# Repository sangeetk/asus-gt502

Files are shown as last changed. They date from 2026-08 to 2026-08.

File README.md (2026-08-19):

# ASUS ROG GT502 — custom aluminium front panel with two touchscreens

A 3 mm aluminium replacement front panel for the ASUS ROG GT502, with two
windows for Waveshare touchscreens bonded from behind with 3M VHB tape. Cutting
the metal away (rather than mounting the screens outside it) is what leaves the
touch surface exposed and usable.

## Files

| File | What it is |
| --- | --- |
| `GT502_front_panel_194x384_both_screens.dxf` | **Everything to be cut.** The panel plus the 4 back stiffener strips, nested on one sheet as a single cutting job. Send this to the laser cutter. |
| `CUTTING_SPEC.txt` | Vendor sheet: material, tolerance, kerf, finish, every coordinate. Send with the DXF. |
| `GT502_front_panel_194x384_both_screens_PRINT_1to1.svg` | True-scale check print. See "Before you order". |
| `GT502_front_panel_194x384_both_screens.svg` | Screen preview, with screen glass and active areas shown as reference. |
| `generate_panel_dxf.py` | Generates all four of the above from the constants at the top. Single source of truth. |
| `name_outlines.py` | Frozen outlines for the two name pieces. Generated offline; imported by the script. |
| `hunabku_outline.py` | Frozen outline for the Hunab Ku keyring. Generated by `trace_hunabku.py`; imported by the script. |
| `trace_hunabku.py` | Traces `hunab_ku_source.svg` into the file above and measures its narrowest metal and slot. Run once; not needed to build the panel. |
| `hunab_ku_source.svg` | The source artwork, public domain, from Wikimedia Commons. |
| `ginger_outline.py` | Frozen outline for the "ginger" lettering. Generated by `trace_ginger.py`; imported by the script. |
| `trace_ginger.py` | Traces `ginger_source.png` into the file above. Run once; not needed to build the panel. |
| `ginger_source.png` | The lettering artwork as supplied — white on transparent, so the shape is in its **alpha channel**. |
| `FrontAluminiumPanel.txt` | Measured outer size of the panel. |
| `Waveshare-11inch.png`, `Waveshare-6.25inch.png` | Manufacturer dimension drawings the screen numbers come from. |

Do not hand-edit the DXF or the spec — change a constant in the script and
re-run it, so the drawing, the print sheet and the spec can never disagree.

## The part

Sheet is **194.00 W × 384.00 H**, 3 mm aluminium, 3.0 mm corner radius.
Origin for all coordinates is the **lower-left corner**, X right, Y up.

| Feature | Size | Position (lower-left) |
| --- | --- | --- |
| Upper window — 6.25″, landscape | 147.18 × 68.70, R2 | X 26.41, Y 287.49 |
| Lower window — 11″, portrait | 153.22 × 241.67, R2 | X 23.39, Y 27.81 |
| Mounting holes, 4 off | Ø3.20 through | see below |

The DXF also carries 7 back stiffener pieces nested **inside** the 11″ window —
see "Back stiffener layer" — two name pieces nested inside the 6.25″ window, and
a Hunab Ku keyring plus the "ginger" lettering in what was left of the 11″
window. Sheet extent stays **194 × 384**, so none of them cost extra material.
One job, one sheet, **12 parts delivered**.

Aluminium between the two windows: **18.00 mm**. Both windows sit **3.00 mm
right of the sheet centreline** — this is deliberate, from test-fitting the
first cut sheet. Left and right margins are *not* equal; work to coordinates.

### Mounting holes

| Hole | X, Y | As measured |
| --- | --- | --- |
| top left | 65.00, 371.00 | 65 from left, 13 from top |
| top right | 135.00, 371.00 | 59 from right, 13 from top |
| bottom left | 32.00, 17.00 | 32 from left, 17 from bottom |
| bottom right | 165.00, 17.00 | 29 from right, 17 from bottom |

All to hole **centre**. Not a symmetric pattern: the top pair is 70.00 apart and
3.0 mm off-centre, the bottom pair 133.00 apart and 1.5 mm off-centre. These
came off the case, so they are correct as given rather than tidy.

**All four moved off the A4 1:1 check prints held against the case.** Top left
+2.00 right, top right +1.00 right; bottom left +2.00 right and +1.00 up, bottom
right +1.00 right and +1.00 up. Each pair's two corrections differ, so both
pitches closed — top 71.00 → 70.00, bottom 134.00 → 133.00 — and neither pair is
symmetric about the sheet any more. That is what four independent measurements
against the real case give you; it is not a pattern being nudged.

Both bottom holes are now **1 mm nearer the 11″ glass**, which is the one
clearance these moves eat into — see "Assembly notes".

> **Open item — hole diameter is an assumption.** Ø3.20 is M3 clearance,
> chosen because no fastener was specified. Confirm before cutting; holes are
> the one feature you cannot correct afterwards. Change `HOLE_DIA` if wrong.

## Screens

Numbers taken from the Waveshare drawings in this folder.

| | Glass (outer) | Active area | Bezel |
| --- | --- | --- | --- |
| 11″, portrait | 165.22 × 253.67 | 148.02 × 236.47 | 8.60 all round |
| 6.25″, landscape | 159.18 × 74.70 | 144.18 × 66.60 | 7.50 sides, 4.05 top/bottom |

Each window is smaller than the glass but larger than the active area, so the
metal overlaps the black bezel and no pixels are clipped.

### VHB tape land

The overlap between metal and bezel is the only place tape can go:

| | Land available |
| --- | --- |
| 11″ | 6.0 mm all four edges |
| 6.25″ | 6.0 mm sides, 3.0 mm top and bottom |

**12 mm VHB will not fit anywhere.** The widest bezel on either screen is
8.60 mm, and the 6.25″ has only 4.05 mm top and bottom — this is a limit of the
screens, not of the drawing. Slit 12 mm tape lengthwise into 6 mm strips, or
buy a 6 mm roll (3M 5952 and GPH both come in 6 mm). Never let tape overhang
into a window: the grey foam shows through the glass.

The 6.0 mm land also leaves 2.60 mm of visible black border around the 11″
image (1.50 / 1.05 mm on the 6.25″). That border is your placement tolerance —
VHB gives you exactly one attempt, so it is margin worth keeping.

## Back stiffener layer

A second 3 mm layer bonded to the **back** of the panel to stiffen it. **7
separate pieces**, all nested inside the 11″ window opening — that slug is
scrap anyway, so they use no extra sheet and the total extent stays 194 × 384.
None of it is visible in the finished build.

| Piece | Bounding size | Bonds at | Shape | Holes |
| --- | --- | --- | --- | --- |
| left strip A | 17.00 × 192.00 | X 0, Y 0 | rect, R3 bottom-left | — |
| left strip B | 20.00 × 192.00 | X 0, Y 192 | **stepped** 17→20, R3 top-left | — |
| right strip A | 11.00 × 192.00 | X 183, Y 0 | rect, R3 bottom-right | — |
| right strip B | 14.00 × 192.00 | X 180, Y 192 | **stepped** 11→14, R3 top-right | — |
| top strip | 160.00 × 24.50 | X 20, Y 359.50 | rect | 2 |
| bottom strip | 166.00 × 21.50 | X 17, Y 0 | rect | 2 |
| mid bar | 160.00 × 8.50 | X 20, Y 275.74 | rect | — |

Three details that are easy to lose, and all three are in the cutting spec:

- **The side pieces each carry one R3 corner** — the one that lands at a panel
  corner. That lets them run the panel's full 384 mm (2 × 192) instead of
  stopping at the corner arc tangents, which cost 6 mm per side.
- **The two upper side pieces are stepped, not rectangular.** They are 17/11 mm
  wide alongside the 11″ glass and widen to 20/14 mm above it. See below.
- **The three horizontals are drawn rotated 90°** from how they are fitted, to
  nest inside the window. Their holes rotate with them.

### Why the side pieces step

The 6.25″ glass is 159.18 wide against the 11″'s 165.22, so it sits 3.02 mm
inboard on each side. A full-height rectangular rail has to be sized for the
wider screen, which leaves a 3.41 mm gap beside the top screen. Stepping the
rail above the 11″ glass closes that to **0.41 mm** without adding pieces or
butt joints. The step sits at Y 275.74 — the top of the 11″ glass plus 0.25 mm
of air, the same line the mid bar sits on.

### Clearances — all four edges run tight

Widths are capped from the live glass positions, not chosen freely: the screens
bond to the panel's own cutouts, so a piece reaching under the glass would sit
that screen on a 3 mm step and tilt it.

| Edge | Free margin | Cut at | Clearance |
| --- | --- | --- | --- |
| left, lower | 17.39 | 17.00 | 0.39 |
| left, upper | 20.41 | 20.00 | 0.41 |
| right, lower | 11.39 | 11.00 | 0.39 |
| right, upper | 14.41 | 14.00 | 0.41 |
| top | 24.81 | 24.50 | 0.31 |
| bottom | 21.81 | 21.50 | 0.31 |
| mid bar | 9.00 gap | 8.50 | 0.25 each side |

**Everything hangs off where the 11″ screen ends up.** Six of those clearances
are under 0.5 mm, and they are all measured from that screen's glass. Bond the
11″ first, measure the actual gaps, then fit the pieces — they are plain
stock you can file, the screen is not.

### The mid bar

Sits in the 9.00 mm gap between the two screens, 8.50 wide with 0.25 mm of air
each side. Its job is to give the 6.25″ screen a bottom edge to sit down onto —
nothing else locates that screen vertically, since it is a small screen in a
large window with only 3 mm of bezel overlap top and bottom. With the 24.50 mm
top strip above it, the 6.25″ glass is captured in a 75.265 mm slot for a
74.700 mm glass: **0.565 mm total slack**.

Fit order matters: **mid bar before the 6.25″ screen**, or it is no use as a
datum. Full sequence — 11″ screen, mid bar, 6.25″ screen, then the perimeter
pieces.

### Holes in the pieces

Top and bottom strips carry matching Ø3.20 holes so one screw passes through
both layers. Offsets are from each piece's own lower-left corner **as drawn**:

| Piece | Holes | Pitch |
| --- | --- | --- |
| top strip | (13.00, 45.00) and (13.00, 115.00) | 70.00 |
| bottom strip | (4.50, 15.00) and (4.50, 148.00) | 133.00 |

Those pitches match the panel's top and bottom hole pitches exactly. The four
side pieces have no holes.

### Nest

The 7 pieces occupy 140.50 of the 143.22 mm available across the window, with
4 mm between pieces and a 5 mm margin to the window edge. **That is full** —
there is no room for another piece or another width increase without starting a
second row. The unused height above the pieces is the only spare space left,
and it is now full too: 65.22 × 61.67 above the three shorter pieces holds the
keyring, and the 79.61 × 35.67 band above the four tall ones holds the
lettering.

The spec tells the cutter to **cut all 7 pieces before the window outline that
surrounds them** — once that contour is cut, the slug they sit in drops away.

## Hunab Ku keyring

One more part, cut from the last of the 11″ window slug: the Mayan Hunab Ku
symbol as a keyring, **54.00 mm outside diameter, 60.60 mm overall** with its
lug, drawn at X 112.00, Y 203.35. Ø3.50 keyring hole. It costs no sheet, it
touches nothing, and dropping it changes nothing else — `MEDALLION = False`.

The outline is traced from `hunab_ku_source.svg` (public domain, Wikimedia
Commons) by `trace_hunabku.py`, which flattens the artwork's single even-odd
path, replaces its disc with a true circle, normalises to a 100 mm nominal
diameter, and freezes the result in `hunabku_outline.py`. The panel script only
scales it.

### Its size is set by the artwork, not by taste

Every line in the symbol scales with the disc, and at a 100 mm disc the
narrowest metal is **1.77 mm** and the narrowest slot **1.81 mm** — both in the
eight antennae. Those numbers come off the geometry itself: the tracer
rasterises the finished outline, opens it morphologically, and measures each
surviving thin feature by its own largest inscribed circle.

At the 52 mm the free space allows, that scales to **0.92 mm metal and 0.94 mm
slots**. That is the finest work on the sheet — finer than the 1.1 mm necks in
the name pieces — so the size is pushed as large as the space allows rather
than down to a pocket-sized fob. **A keyring-sized 40 mm version would need
0.7 mm slots and is not worth sending to a cutter.** The spec asks the vendor to
confirm they can hold 0.9 mm in 3 mm aluminium, and to say so rather than
opening the slots out. `MEDAL_MIN_FEATURE` makes the script refuse to draw it
below 0.85 mm.

### Two things added to the artwork

- **The rim is drawn 1.00 mm outside the symbol's own disc** (`MEDAL_RIM_EXTRA`).
  The artwork's outer ring is as thin as everything else in it, and that ring is
  what the keyring hangs off. Doubling it up reads as a slightly heavier rim and
  moves nothing else.
- **A lug on top**, filleted into the disc, carrying the hole — 2.25 mm of metal
  around it. There is nowhere inside the symbol to put a hole: the widest solid
  area in it takes only a 10 mm circle, off to one side, so a hole there would
  deface it *and* hang it crooked.

The piece is **one connected part** — the symbol's material is a single region,
so every internal contour is a hole that drops out and nothing is a loose
island. That is checked, not assumed. Cut it before the 11″ window outline, same
as the stiffener pieces.

## "ginger" lettering

The last free space in the 11″ slug, the band above the tall stiffener strips,
holds the word **"ginger" at 75.91 × 33.71 mm**, drawn at X 30.24, Y 229.80.
One connected part: 1 outer contour and 4 counters that drop out.

It is **traced artwork, not type** — `ginger_source.png` as supplied, which is
white lettering on a transparent background, so the shape lives in the file's
alpha channel and a viewer that flattens it onto white shows a blank page.
`trace_ginger.py` thresholds that alpha, drops the export's specks and pinholes,
traces the pixel boundary exactly, rounds the 0.09 mm staircase off it and
simplifies. No font is involved, so nothing depends on having the typeface.

Two things worth knowing before it is cut:

- **The dot of the "i" is tied on with a 2.5 mm weld tab.** It is a separate
  shape in the artwork, as it is in any script, and without the tab it arrives
  as a loose disc. Same trick, same width, as the tabs holding the name pieces'
  i-dots and flourishes together. It is drawn into the outline — the cutting
  spec asks the vendor not to "clean up" the join.
- **Narrowest stroke is 1.59 mm**, measured off the finished outline rather
  than guessed at. That is half again the 1.06–1.12 mm necks in the name
  pieces, so the lettering asks nothing unusual of the cutter, and it is why no
  fattening was needed here.

Size is not a constant in the panel script — it is baked into
`ginger_outline.py`, because the weld tab is a fixed 2.5 mm and must not scale
with the word. Change `TARGET_W` in the tracer and re-run it. 76 mm is what the
free band allows; the piece is 33.71 tall in a 35.67 mm gap.

## Before you order

1. Print `..._PRINT_1to1.svg` at **100% / actual size** — no fit-to-page. It is
   194 × 384, so use **A3**. Check the scale bar reads 100 mm, then lay the real
   screens and the cut sheet on it.
2. Confirm the hole diameter (above).
3. Check depth clearance: the 11″ is ~12 mm deep with its connectors.

## Assembly notes

Everything bonds to the **back** face, which must be flat and deburred. The
order matters, because several pieces are datums for the ones after them and
six clearances are under 0.5 mm.

1. **Fit the two bottom screws first.** Those holes sit 3.21 mm from the 11″
   glass edge — 1 mm tighter since they moved up; an M3 head (~6 mm OD) leaves
   1.81 mm and a washer (~7 mm) 1.31.
   It fits, but not with a screwdriver in the way once the screen is on.
   Anything with a flange over ~11 mm OD will touch the glass.
2. **Bond the 11″ screen**, centred in its window. Everything else is measured
   from it. VHB gives you one attempt.
3. **Measure the real gaps** left and right before any side piece goes on. You
   need ≥ 17.4 mm left and ≥ 11.4 mm right against the lower rails, and
   ≥ 20.4 / ≥ 14.4 above the step. If a gap is short, file the inner edge of
   that piece — the pieces are plain stock, the screen is not.
4. **Fit the mid bar**, seated against the 11″ glass top edge.
5. **Set the 6.25″ screen down onto the mid bar.** That bar is the only thing
   locating it vertically.
6. **Fit the remaining pieces** — side rails, top strip, bottom strip.

Other notes:

- Glass-to-glass air gap between the two screens is 9.00 mm; the mid bar takes
  8.50 of it.
- Clean the bezel with IPA before taping. VHB reaches full strength over ~72 h.
- **12 mm VHB will not fit anywhere** — see "VHB tape land". Slit it to 6 mm.
- The bottom strip leaves a 3.90 mm web above each of its holes. Fine, but
  don't overtighten there.

## Regenerating

```sh
python3 generate_panel_dxf.py
```

No dependencies beyond the standard library. It prints every dimension and
clearance it used. Constants worth knowing, all near the top of the script:

| Constant | Meaning |
| --- | --- |
| `PANEL_W`, `PANEL_H` | Sheet outer size |
| `CUT_GAP` | Nominal metal between the two windows |
| `INS_11`, `INS_625` | Per-edge bezel overlap (= the VHB land) |
| `WIN_DX`, `WIN_11_DY`, `WIN_625_DY` | Fit corrections applied to the windows |
| `MOUNT_HOLES`, `HOLE_DIA` | Hole table and diameter |
| `BORDER_REQ`, `BORDER_CLEAR` | Back stiffener widths and per-edge glass clearance |
| `BORDER_MID_BAR`, `BORDER_MID_CLEAR` | The bar between the two screens |
| `BORDER_SIDE_PIECES` | How many pieces each side rail splits into |
| `BORDER_NEST_GAP`, `BORDER_WIN_MARGIN` | Spacing of the nested pieces |
| `MEDALLION`, `MEDAL_ART_DIA` | Whether to cut the keyring, and the traced symbol's disc diameter |
| `MEDAL_RIM_EXTRA`, `MEDAL_MIN_FEATURE` | Rim widening, and the size below which the script refuses to draw it |
| `MEDAL_LUG_R`, `MEDAL_LUG_STANDOFF`, `MEDAL_LUG_FILLET`, `MEDAL_RING_HOLE` | The keyring lug and its hole |
| `GINGER_CUT`, `GINGER_GAP`, `GINGER_MIN_NECK` | Whether to cut the lettering, its clearance, and the stroke width below which the script refuses |
| `WORD` | Set to a string to also emit a variant with text cut into the top band |

The script asserts rather than trusting the numbers: no window may clip an
active area, glass may not overhang any edge, the two screens may not collide
behind the panel, every hole must clear both windows and all four edges, no
stiffener piece may overlap a glass footprint (checked against each piece's real
sub-rectangles, not its bounding box, so a step is not a false positive), every
hole must land in exactly one piece, every nested piece must sit inside the
window with margin, and no piece may overlap the panel or another piece. The
keyring and the lettering add their own: each finds its free rectangle rather
than being told where it is — and the lettering searches with the keyring
counted as an obstacle — so re-nesting the stiffeners moves them instead of
quietly overlapping something, and each refuses to be drawn below its own
minimum feature size. A bad edit fails loudly
instead of producing an uncuttable part.

### Optional cut-through lettering

Setting `WORD` (e.g. `"URANTIA TECH"`) pushes the screens down and cuts text
into the band above the top screen. Glyphs for `A C E H I N P R T U` are built
in as squared monoline caps.

`A`, `P` and `R` are **stencil** letters: each has a fixed-width gap in one bar
tying the middle of the letter to the surrounding metal. Without it the centre
of the letter is an island with nothing holding it, and it drops out of the
sheet during cutting. Do not close those gaps, and tell the vendor not to
substitute a normal font.

## Revision history

- **v1** — cut and test-fitted. Windows were centred on the width; mounting
  holes were a symmetric 28/10 pattern.
- **v2** — corrections measured off the v1 sheet: both windows moved
  3 right; 11″ window 3 down; 6.25″ window 3 up; all four holes repositioned.
  Window-to-window metal went from 12.00 to 18.00 as a direct consequence of
  moving the two screens apart.
- **v3** — added the back stiffener layer as 4 strips nested beside the panel.
- **v4** — stiffener reworked to 7 pieces nested *inside* the 11″
  window, so it costs no extra sheet. Side rails split in two and given the
  panel's R3 corner so they run full height; the upper pair stepped to close the
  gap beside the 6.25″ screen from 3.41 to 0.41. Added the mid bar. Top strip
  widened to 24.50 and bottom to 21.50 so both screens are captured. All cut
  geometry unified to one colour on two kerf-side layers.
- **v5** — two name pieces nested in the 6.25″ window slug; the Hunab Ku
  keyring and the "ginger" lettering nested in what was left of the 11″ window
  slug. 12 parts off one sheet, still 194 × 384.
- **v6 (current)** — all four mounting holes corrected off the A4 1:1 check
  prints against the case: top left +2.00 right, top right +1.00 right, bottom
  left +2.00 right and +1.00 up, bottom right +1.00 right and +1.00 up. Top
  pitch 71.00 → 70.00, bottom 134.00 → 133.00. Both stiffener strips' holes
  follow automatically, since they are derived from the panel's.

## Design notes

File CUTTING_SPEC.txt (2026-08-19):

CUSTOM FRONT PANEL - CUTTING SPECIFICATION
ASUS ROG GT502, aluminium front panel with two touchscreen cutouts
==================================================================

DXF FILE   : GT502_front_panel_194x384_both_screens.dxf
MATERIAL   : Aluminium sheet, 3.0 mm thickness
QUANTITY   : 1 off of everything on the sheet - the panel plus the 7 back
             stiffener pieces nested inside its large window, plus 2
             decorative name pieces nested inside the smaller window, plus
             1 keyring and 1 lettering piece nested in the large
             window above the stiffeners.
             ONE cutting job, 12 parts delivered in total.
PROCESS    : Laser cut (fibre) or waterjet
UNITS      : Millimetres. DXF is AC1009 / R12 ASCII, $INSUNITS = 4 (mm).
GEOMETRY   : Panel outer profile + internal cutouts, plus 7 separate
             stiffener pieces nested INSIDE the large window opening.
             Those pieces are separate parts, NOT features of the panel.
TOLERANCE  : +/- 0.15 mm on all cutout sizes and positions.
LAYERS     : Every contour in this file is a THROUGH-CUT. There is no
             engraving, scoring or rastering anywhere in the drawing, and
             nothing in it should be treated as such.
             All geometry is drawn in ONE colour (red, ACI 1) so there is no
             colour mapping to interpret. Two layers are used purely to say
             which side of the line the kerf belongs on:
               CUT_OUTER  part boundaries - the panel profile and the
                          outline of every separate part nested inside it
               CUT_INNER  openings - windows, holes, and every internal
                          contour of a nested part
             If your workflow needs everything on a single layer, merging
             them is fine; the layer names carry no operation meaning.
KERF       : Geometry is NOMINAL. Please apply your own kerf compensation so
             the finished part matches the drawing: outer profile cut on the
             outside of the line, windows cut on the inside of the line.
FINISH     : Deburr both faces. The window edges must be flat and burr-free -
             a touchscreen is bonded to the BACK face around each opening
             with 3M VHB tape, so the back face must be clean and flat.
             No anodising / powder coat unless quoted separately.

DIMENSIONS (origin = lower-left corner of the sheet, X right, Y up)
------------------------------------------------------------------
Sheet outline        194.00 W x 384.00 H, corner radius 3.0

Window 1 - upper, small (6.25 inch screen, landscape)
   size              147.18 W x 68.70 H, corner radius 2.0
   lower-left at     X 26.41 , Y 287.49

Window 2 - lower, large (11 inch screen, portrait)
   size              153.22 W x 241.67 H, corner radius 2.0
   lower-left at     X 23.39 , Y 27.81

Vertical gap between the two windows   18.00
Both windows sit 3.00 to the RIGHT of the sheet centreline, so the
left and right margins are NOT equal. Please work to the X/Y
coordinates above rather than centring anything.

Mounting holes - 4 off, diameter 3.20 THROUGH
   top left      X   65.00 , Y  371.00   (65.00 from left, 13.00 from top)
   top right     X  135.00 , Y  371.00   (59.00 from right, 13.00 from top)
   bottom left   X   32.00 , Y   17.00   (32.00 from left, 17.00 from bottom)
   bottom right  X  165.00 , Y   17.00   (29.00 from right, 17.00 from bottom)
   All hole positions are to the CENTRE. They are NOT a symmetric pattern -
   please work to the coordinates as given.
Aluminium remaining below lower window 27.81
Aluminium remaining above upper window 27.81

NOTES
------------------------------------------------------------------
- The 4 mounting holes above are the only fixings in this drawing. No
  clip or latch features are included. Please cut only what is in the DXF.
- Do not scale the drawing. All dimensions are final.

BACK STIFFENER PIECES - 7 pieces, same 3 mm aluminium
------------------------------------------------------------------
These are SEPARATE PARTS nested INSIDE the large 11 inch window opening.
That material is being removed anyway, so they use no extra sheet: total
sheet extent stays 194.00 x 384.00, the panel size.

** CUT ORDER: please cut these 7 pieces BEFORE cutting the large window
   outline that surrounds them. Once the window contour is cut the slug
   they sit in drops away. **

** CUT EVERY PIECE EXACTLY AS DRAWN. Do not simplify any of them to a
   plain rectangle. 4 of the 7 have a rounded corner, and 2 of
   those are STEPPED (wider along part of their length). The sizes quoted
   below are BOUNDING sizes - the true outline is in the DXF geometry. **

They bond flat to the BACK of the panel and are not visible in the
finished build.

   LEFT STRIP A     bounding size 17.00 W x 192.00 H   drawn at X 28.39, Y 32.81
      shape: plain rectangle, R3.0 on the bottom-left corner.
      no holes

   LEFT STRIP B     bounding size 20.00 W x 192.00 H   drawn at X 49.39, Y 32.81
      shape: STEPPED, not a rectangle.
             17.00 wide for the first 83.74 of its length, then 20.00 wide for the
             remaining 108.26. The step is on the INNER edge; the outer edge
             is straight. R3.0 on the top-left corner.
      no holes

   RIGHT STRIP A    bounding size 11.00 W x 192.00 H   drawn at X 73.39, Y 32.81
      shape: plain rectangle, R3.0 on the bottom-right corner.
      no holes

   RIGHT STRIP B    bounding size 14.00 W x 192.00 H   drawn at X 88.39, Y 32.81
      shape: STEPPED, not a rectangle.
             11.00 wide for the first 83.74 of its length, then 14.00 wide for the
             remaining 108.26. The step is on the INNER edge; the outer edge
             is straight. R3.0 on the top-right corner.
      no holes

   TOP STRIP        bounding size 24.50 W x 160.00 H   drawn at X 106.39, Y 32.81
      shape: plain rectangle, square corners.
      NOTE: drawn rotated 90 deg from how it is fitted.
      hole at X 13.00, Y 45.00
      hole at X 13.00, Y 115.00

   BOTTOM STRIP     bounding size 21.50 W x 166.00 H   drawn at X 134.89, Y 32.81
      shape: plain rectangle, square corners.
      NOTE: drawn rotated 90 deg from how it is fitted.
      hole at X 4.50, Y 15.00
      hole at X 4.50, Y 148.00

   MID BAR          bounding size 8.50 W x 160.00 H   drawn at X 160.39, Y 32.81
      shape: plain rectangle, square corners.
      NOTE: drawn rotated 90 deg from how it is fitted.
      no holes

Strip hole positions are offsets from that strip's own lower-left corner
and match the panel holes, so one screw passes through both layers.
Deburr both faces - these bond flat against the panel.

DECORATIVE NAME PIECES - 2 off, same 3 mm aluminium
------------------------------------------------------------------
Nested inside the SMALLER (6.25 inch) window opening - again,
scrap material, so no extra sheet is used.

** CUT ORDER: cut these before the 6.25 inch window outline that
   surrounds them, for the same reason as the stiffener pieces. **

Each name is ONE connected piece of script lettering. The outer
contour is the part boundary; the inner contours are letter
counters and drop out. Curves are supplied as fine polylines -
please cut them as drawn, do not re-fit arcs or smooth them.

   Amishi     81.51 W x  23.10 H   at X 59.25, Y 293.48   (3 contours)
   Mayan      84.94 W x  29.61 H   at X 57.53, Y 320.58   (4 contours)

Typeface: Floraison des Amours. Narrowest neck in the lettering is 1.06 mm
and that is deliberate and cuttable in 3 mm. Please cut the
outlines exactly as supplied: do not smooth them, do not re-fit
arcs, and do not thin or thicken the strokes.

HUNAB KU KEYRING - 1 off, same 3 mm aluminium
------------------------------------------------------------------
One more separate part, nested inside the LARGE (11 inch) window above
the stiffener pieces. Scrap material again, so no extra sheet.

** CUT ORDER: cut this piece BEFORE the 11 inch window outline, same
   reason as the stiffener pieces. **

   bounding size    54.00 W x 60.60 H, drawn at X 112.00, Y 203.35
   disc             54.00 diameter, centre X 139.00, Y 230.35
   keyring hole     3.50 diameter THROUGH at X 139.00, Y 259.95
   contours         1 outer boundary + 3 internal + the keyring hole

** THE NARROWEST METAL IN THIS PART IS 0.92 mm AND THE NARROWEST SLOT
   0.94 mm. ** That is the finest work on the sheet. Please confirm you
   can hold it in 3 mm aluminium before cutting; if you cannot, say so
   rather than opening the slots out, and this part will be dropped or
   redrawn. Nothing else on the sheet depends on it.

The outline is a traced symbol, supplied as fine polylines. Cut it exactly
as drawn: do not smooth it, do not re-fit arcs, do not thin or thicken
anything. The stepped edges are meant to be stepped.

The piece is one connected part - every internal contour is a hole that
drops out, and nothing in it is a loose island.

"GINGER" LETTERING - 1 off, same 3 mm aluminium
------------------------------------------------------------------
One more separate part, nested inside the LARGE (11 inch) window beside
the keyring. Scrap material again, so no extra sheet.

** CUT ORDER: cut this piece BEFORE the 11 inch window outline, same
   reason as everything else nested inside it. **

   bounding size    75.91 W x 33.71 H, drawn at X 30.24, Y 229.80
   contours         1 outer boundary + 4 counters, all of which drop out
   narrowest stroke 1.59 mm

This is ONE connected piece of brush lettering, traced from artwork - not
type. The dot of the "i" is a separate shape in the artwork and is tied to
the letter below it by a 2.5 mm WELD TAB drawn into the outline. Without
that tab the dot is a loose disc. Please cut the outline exactly as
supplied: do not remove the tab, do not smooth the curves, do not re-fit
arcs, and do not thin or thicken the strokes.

Curves are supplied as fine polylines, which is what tracing artwork
gives; they are already simplified and are meant to be cut as they are.

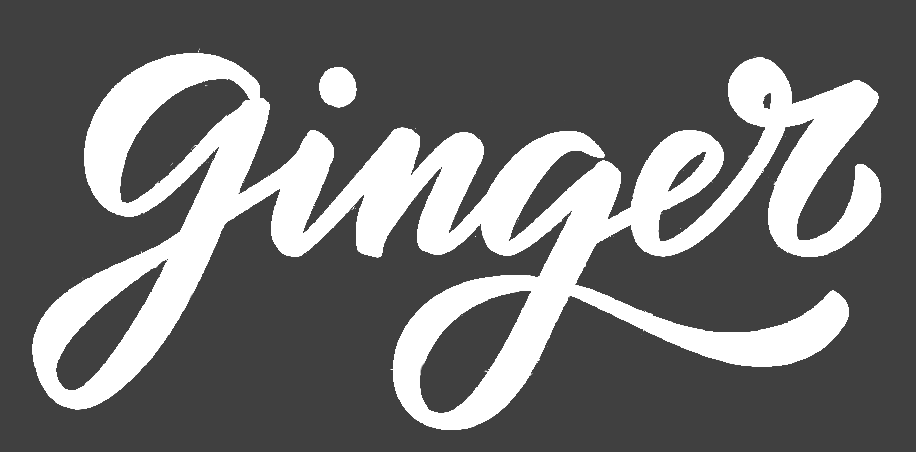
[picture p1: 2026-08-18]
ginger_source.png

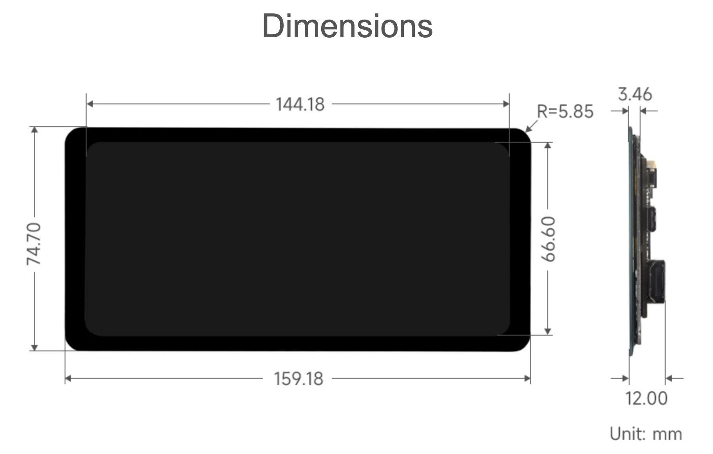
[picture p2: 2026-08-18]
Waveshare-6.25inch.png

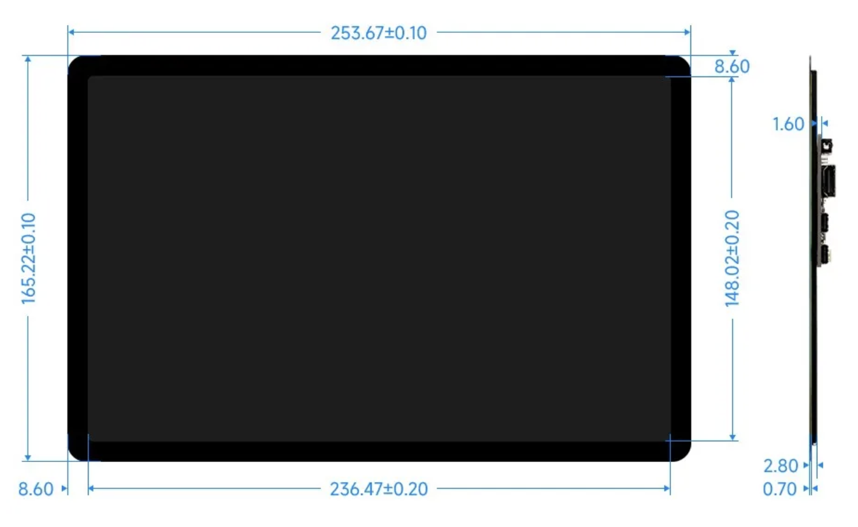
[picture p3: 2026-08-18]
Waveshare-11inch.png

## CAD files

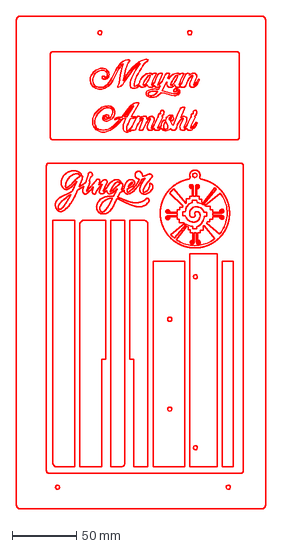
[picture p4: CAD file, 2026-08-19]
GT502_front_panel_194x384_both_screens.dxf
194.0 x 384.0 mm

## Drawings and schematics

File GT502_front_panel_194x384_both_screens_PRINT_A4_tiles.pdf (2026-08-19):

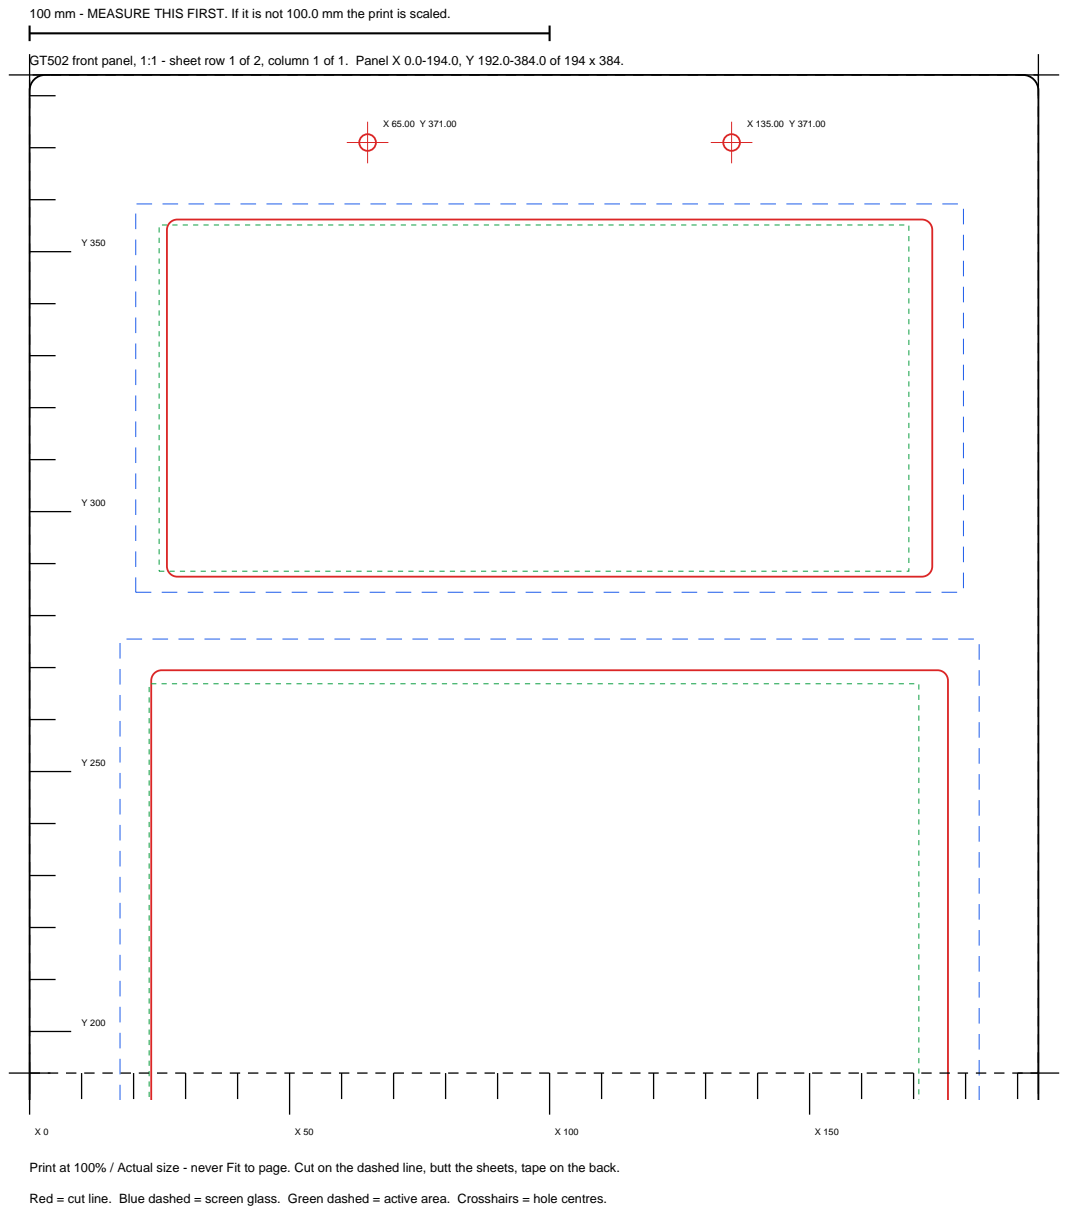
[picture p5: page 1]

100 mm - MEASURE THIS FIRST. If it is not 100.0 mm the print is scaled.

GT502 front panel, 1:1 - sheet row 1 of 2, column 1 of 1. Panel X 0.0-194.0, Y 192.0-384.0 of 194 x 384.

Print at 100% / Actual size - never Fit to page. Cut on the dashed line, butt the sheets, tape on the back.

Red = cut line. Blue dashed = screen glass. Green dashed = active area. Crosshairs = hole centres.

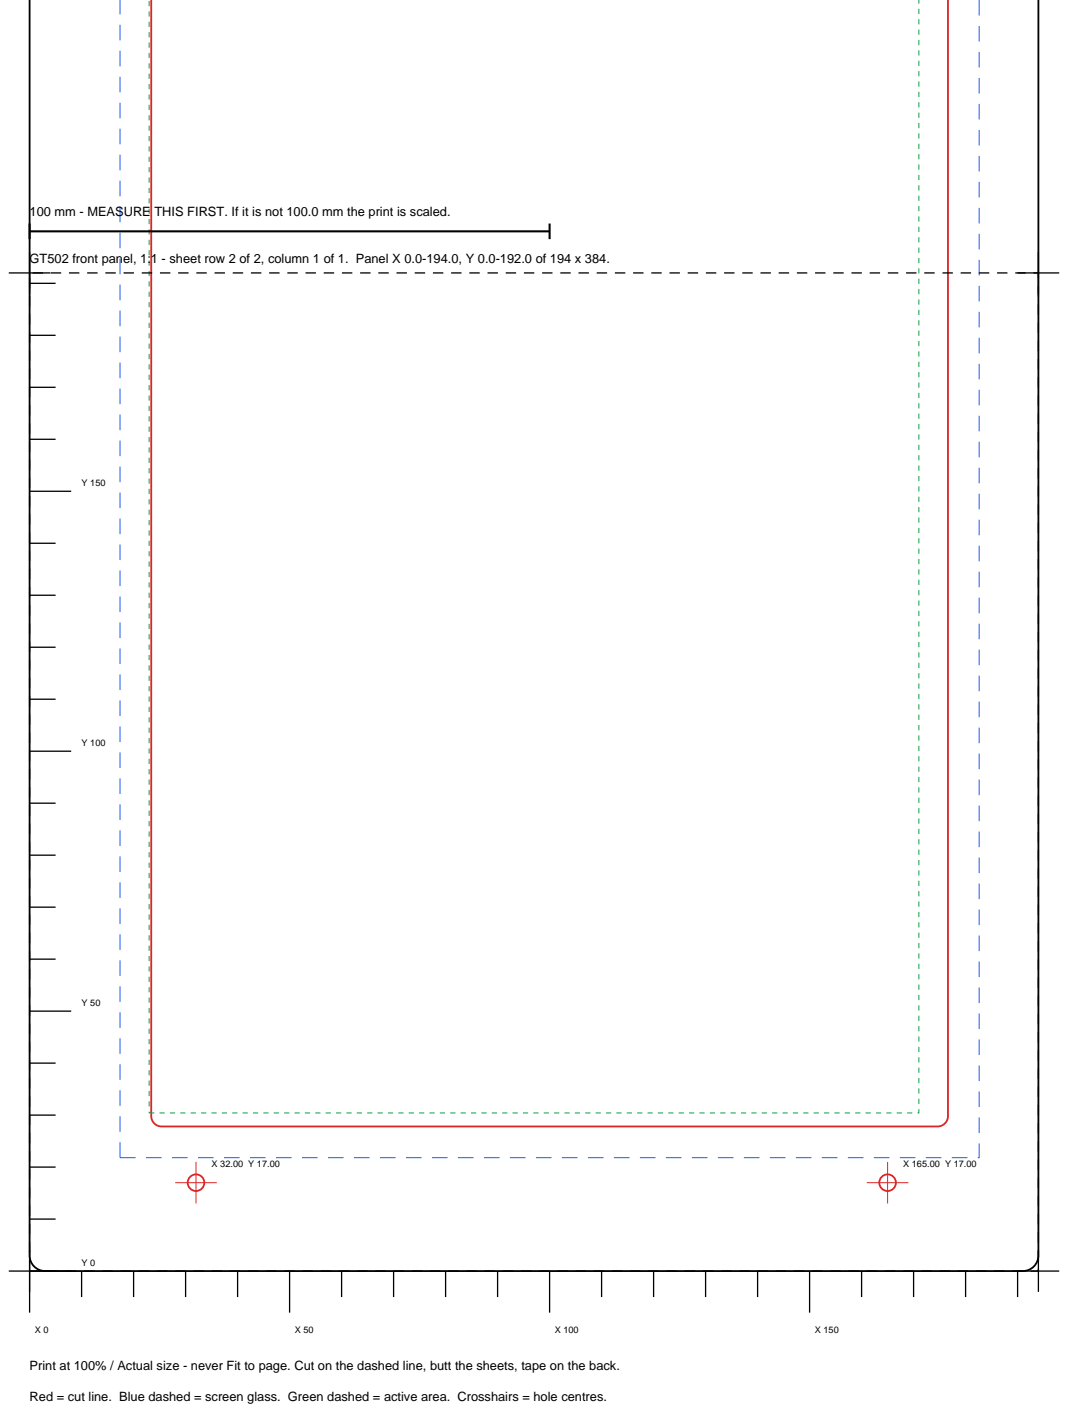
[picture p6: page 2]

100 mm - MEASURE THIS FIRST. If it is not 100.0 mm the print is scaled.

GT502 front panel, 1:1 - sheet row 2 of 2, column 1 of 1. Panel X 0.0-194.0, Y 0.0-192.0 of 194 x 384.

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

Red = cut line. Blue dashed = screen glass. Green dashed = active area. Crosshairs = hole centres.

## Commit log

2026-08-18 side support
    [GT502_front_panel_194x384_both_screens.dxf]
2026-08-18 more closer support
    [GT502_front_panel_194x384_both_screens.dxf]
2026-08-18 rounded corners in support strip
    [GT502_front_panel_194x384_both_screens.dxf]
2026-08-18 more tight fitting
    [GT502_front_panel_194x384_both_screens.dxf]
2026-08-18 Amishi Mayan
    [GT502_front_panel_194x384_both_screens.dxf]
2026-08-18 added hunabku and ginger
    [GT502_front_panel_194x384_both_screens.dxf]
2026-08-19 almost final
    [GT502_front_panel_194x384_both_screens.dxf]
